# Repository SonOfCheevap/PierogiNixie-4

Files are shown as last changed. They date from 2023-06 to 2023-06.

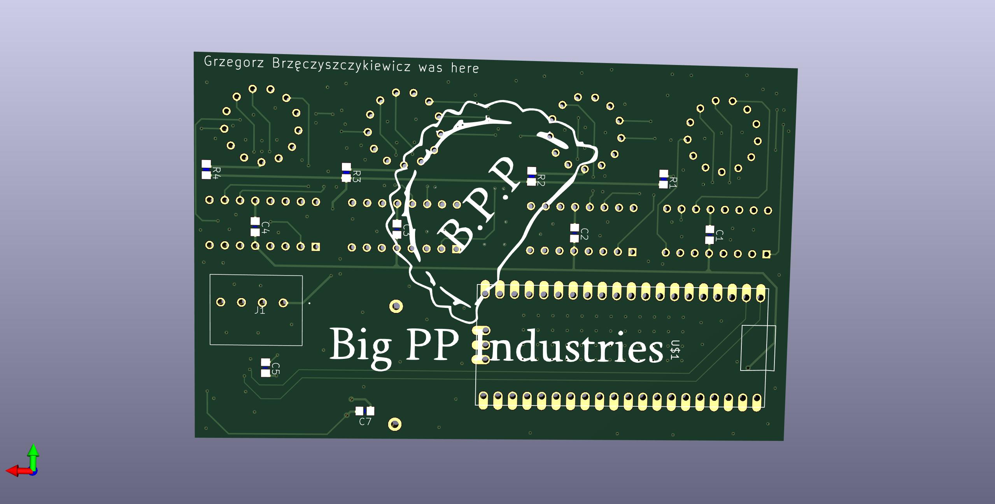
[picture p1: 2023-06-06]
Pictures/back.jpg

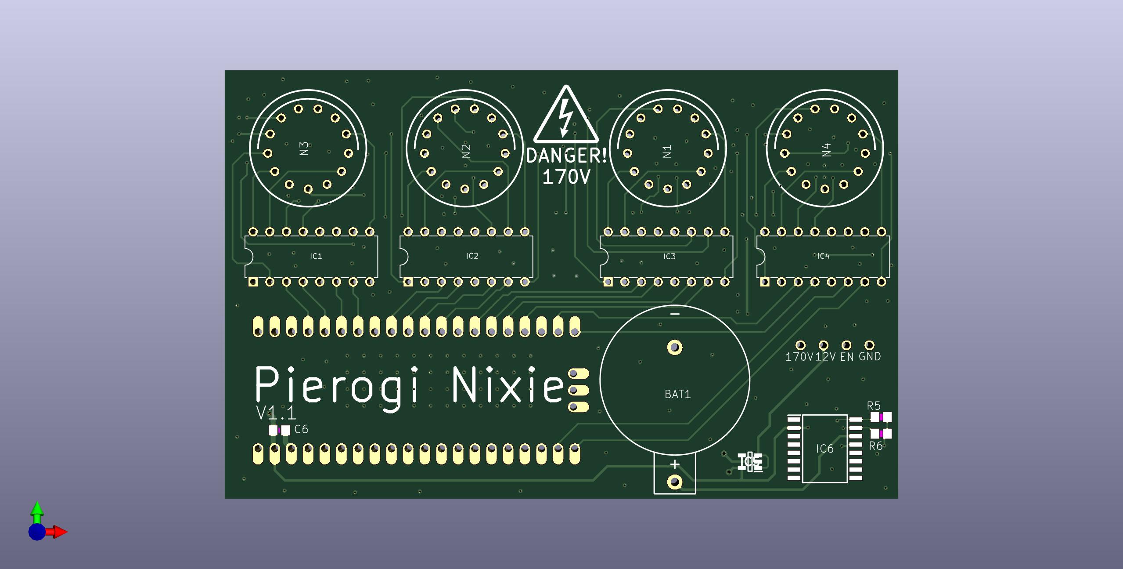
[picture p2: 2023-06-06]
Pictures/front.jpg

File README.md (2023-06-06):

# PierogiNixie-4
A Pi Pico powered nixie tube board that uses 4 IN-14 nixie tubes.

# Features
- Programmed using a Pi Pico
- ds3231m RTC
- CR2032 Battery for keeping time when off power
- 4x IN-14 Nixie Tubes
- 4x k155id1 Binary to Decimal decoders
- Onboard 12v to 5v Convertor

# Photos
Front

front

Back

back

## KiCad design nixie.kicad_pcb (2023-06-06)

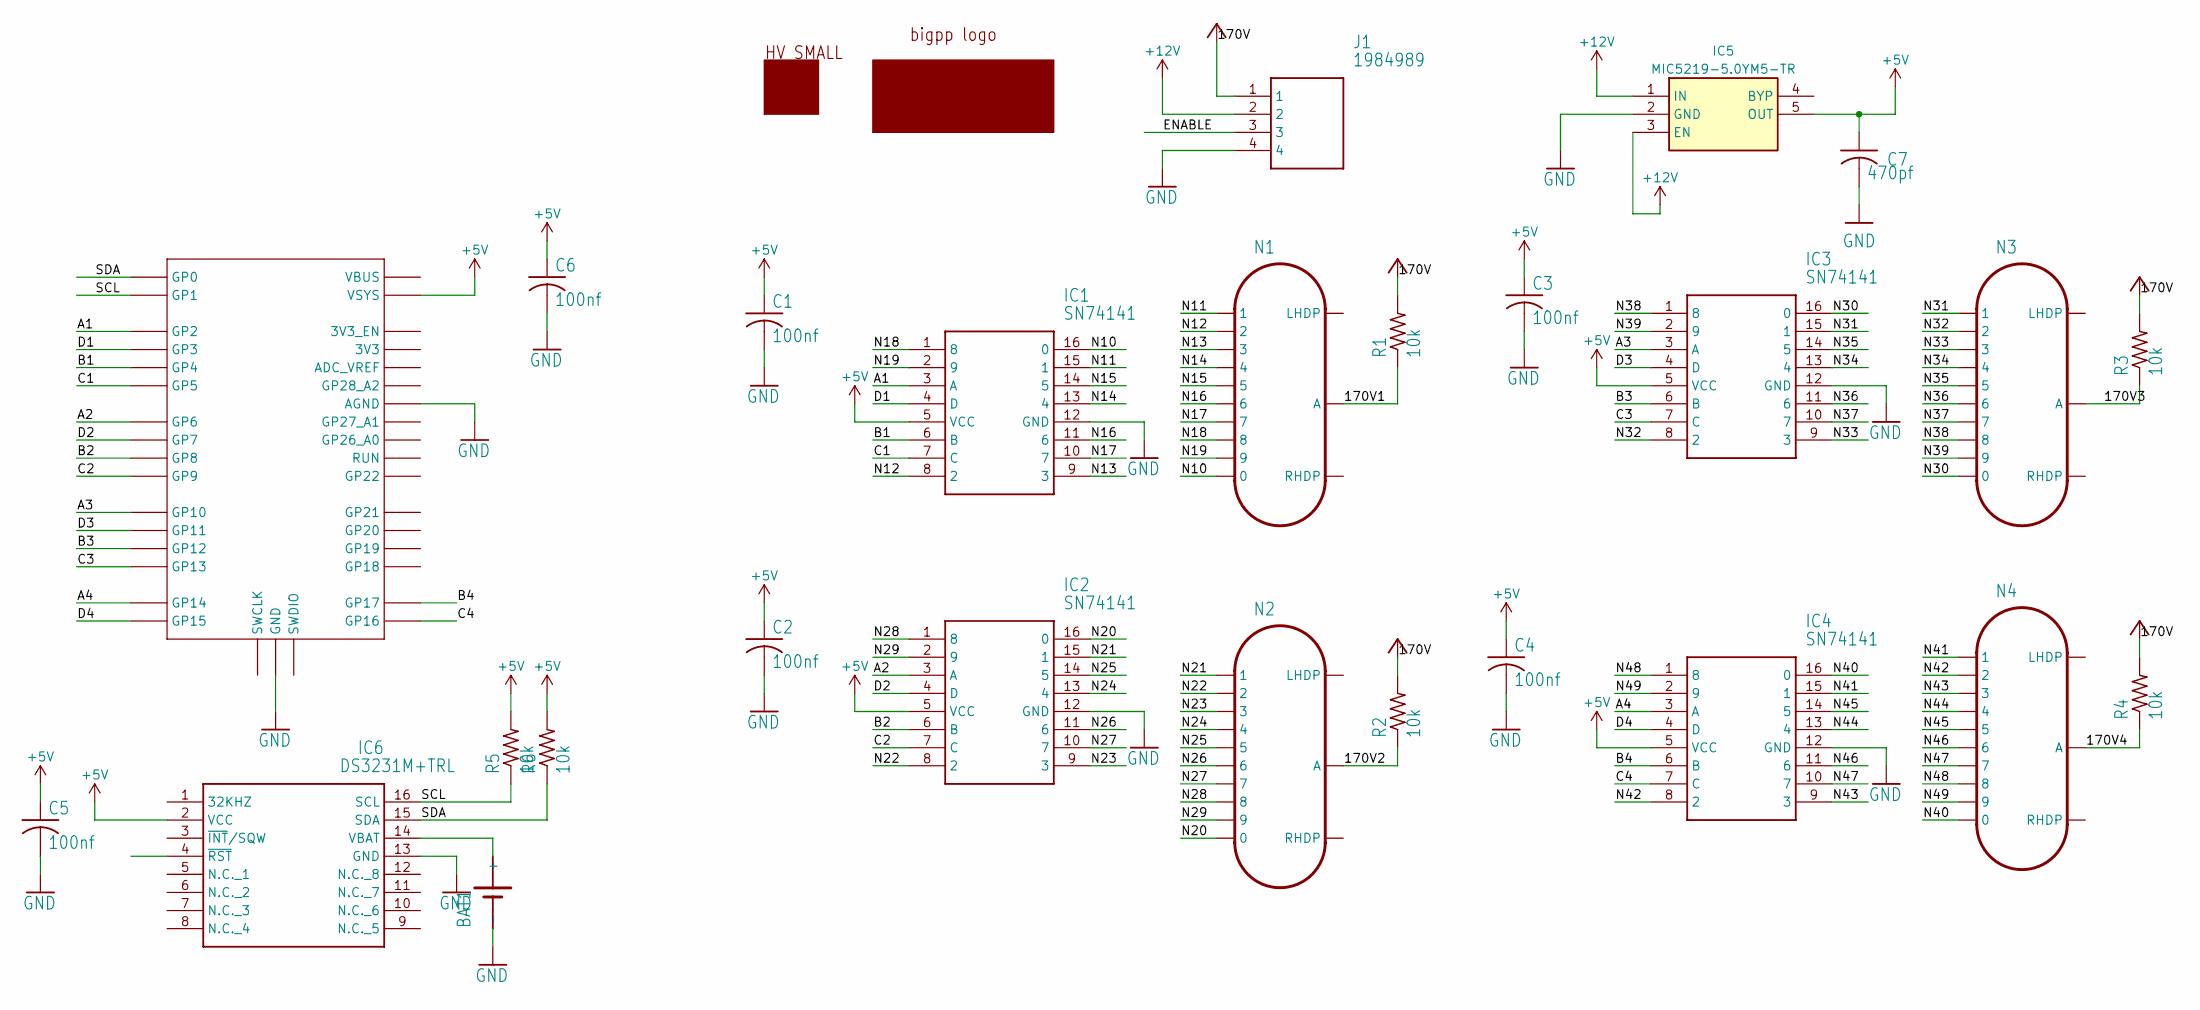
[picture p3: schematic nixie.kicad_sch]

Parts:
BAT1: SN2032
C1, C2, C3, C4, C5, C6: 100nf; C0805
C7: 470pf; C0805
IC1, IC2, IC3, IC4: SN74141; DIP16-2.54-19.2X7.62MM
IC5: MIC5219-5.0YM5-TR; SOT95P280X130-5N; Manufacturer_Part_Number MIC5219-5.0YM5-TR; Mouser Part Number 998-MIC5219-5.0YM5TR
IC6: DS3231M+TRL; SOIC127P1032X265-16N
J1: 1984989
N1, N2, N3, N4: IN-14
R1, R2, R3, R4, R5, R6: 10k; R0805
U$1: RPI_PICO-TH; RPI_PICO_TH
U$2: HVSMALL
U$3: BIGPP

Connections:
+5V: C1.1, C2.1, C3.1, C4.1, C5.1, C6.1, C7.1, IC1.5 (VCC), IC2.5 (VCC), IC3.5 (VCC), IC4.5 (VCC), IC5.5 (OUT), IC6.2 (VCC), R5.2, R6.2, U$1.VSYS
+12V: IC5.1 (IN), IC5.3 (EN), J1.2
/170V1: N1.A, R1.1
/170V2: N2.A, R2.1
/170V3: N3.A, R3.1
/170V4: N4.A, R4.1
/A1: IC1.3 (A), U$1.GP2
/A2: IC2.3 (A), U$1.GP6
/A3: IC3.3 (A), U$1.GP10
/A4: IC4.3 (A), U$1.GP14
/B1: IC1.6 (B), U$1.GP4
/B2: IC2.6 (B), U$1.GP8
/B3: IC3.6 (B), U$1.GP12
/B4: IC4.6 (B), U$1.GP17
/C1: IC1.7 (C), U$1.GP5
/C2: IC2.7 (C), U$1.GP9
/C3: IC3.7 (C), U$1.GP13
/C4: IC4.7 (C), U$1.GP16
/D1: IC1.4 (D), U$1.GP3
/D2: IC2.4 (D), U$1.GP7
/D3: IC3.4 (D), U$1.GP11
/D4: IC4.4 (D), U$1.GP15
/ENABLE: J1.3
/N10: IC1.16 (0), N1.0
/N11: IC1.15 (1), N1.1
/N12: IC1.8 (2), N1.2
/N13: IC1.9 (3), N1.3
/N14: IC1.13 (4), N1.4
/N15: IC1.14 (5), N1.5
/N16: IC1.11 (6), N1.6
/N17: IC1.10 (7), N1.7
/N18: IC1.1 (8), N1.8
/N19: IC1.2 (9), N1.9
/N20: IC2.16 (0), N2.0
/N21: IC2.15 (1), N2.1
/N22: IC2.8 (2), N2.2
/N23: IC2.9 (3), N2.3
/N24: IC2.13 (4), N2.4
/N25: IC2.14 (5), N2.5
/N26: IC2.11 (6), N2.6
/N27: IC2.10 (7), N2.7
/N28: IC2.1 (8), N2.8
/N29: IC2.2 (9), N2.9
/N30: IC3.16 (0), N3.0
/N31: IC3.15 (1), N3.1
/N32: IC3.8 (2), N3.2
/N33: IC3.9 (3), N3.3
/N34: IC3.13 (4), N3.4
/N35: IC3.14 (5), N3.5
/N36: IC3.11 (6), N3.6
/N37: IC3.10 (7), N3.7
/N38: IC3.1 (8), N3.8
/N39: IC3.2 (9), N3.9
/N40: IC4.16 (0), N4.0
/N41: IC4.15 (1), N4.1
/N42: IC4.8 (2), N4.2
/N43: IC4.9 (3), N4.3
/N44: IC4.13 (4), N4.4
/N45: IC4.14 (5), N4.5
/N46: IC4.11 (6), N4.6
/N47: IC4.10 (7), N4.7
/N48: IC4.1 (8), N4.8
/N49: IC4.2 (9), N4.9
/SCL: IC6.16 (SCL), R5.1, U$1.GP1
/SDA: IC6.15 (SDA), R6.1, U$1.GP0
GND: BAT1.-, C1.2, C2.2, C3.2, C4.2, C5.2, C6.2, C7.2, IC1.12 (GND), IC2.12 (GND), IC3.12 (GND), IC4.12 (GND), IC5.2 (GND), IC6.13 (GND), J1.4, U$1.AGND, U$1.GND@1 (GND), U$1.GND@2 (GND), U$1.GND@3 (GND), U$1.GND@4 (GND), U$1.GND@5 (GND), U$1.GND@6 (GND), U$1.GND@7 (GND), U$1.GND@8 (GND)
unnamed: BAT1.+, IC6.14 (VBAT)
VCC: J1.1, R1.2, R2.2, R3.2, R4.2

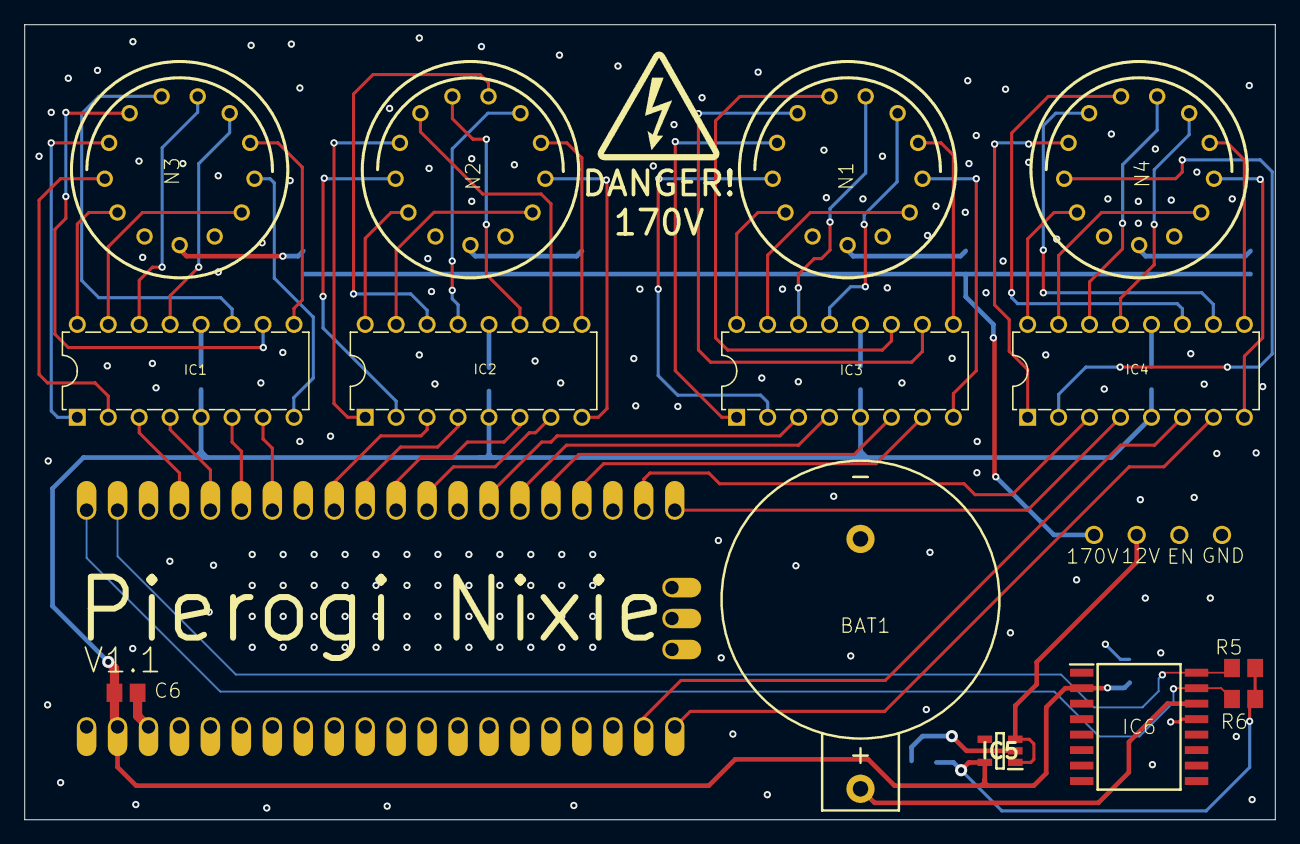
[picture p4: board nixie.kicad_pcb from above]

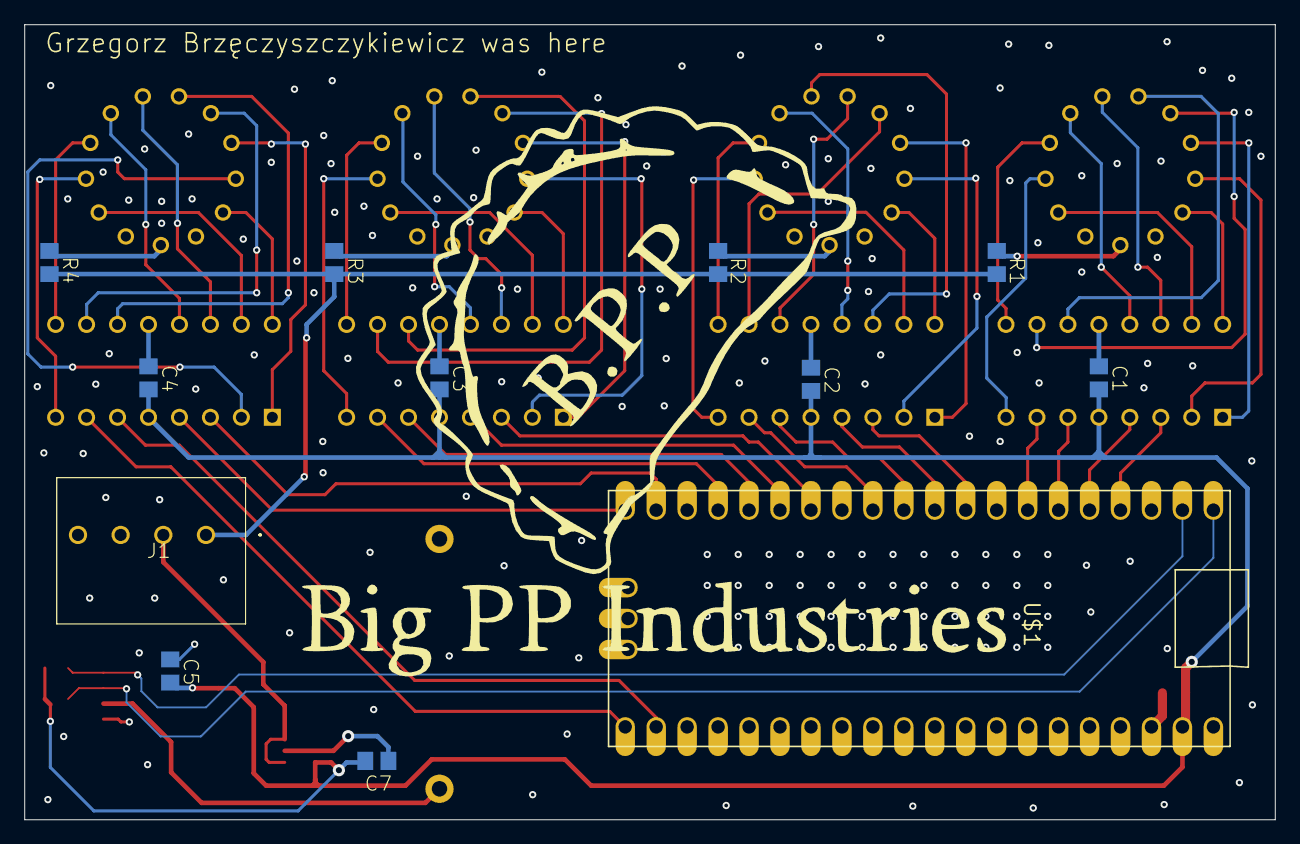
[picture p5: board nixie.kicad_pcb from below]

Board: 4 copper layers, 102.6 x 65.2 mm, 27 parts (16 on the bottom side), 67 nets.

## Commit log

2023-06-06 Add files via upload
    Project files + Gerber
    [nixie.kicad_pcb, nixie.kicad_sch]
2023-06-23 Adding WIP files
    [nixie.kicad_pcb, nixie.kicad_sch]
